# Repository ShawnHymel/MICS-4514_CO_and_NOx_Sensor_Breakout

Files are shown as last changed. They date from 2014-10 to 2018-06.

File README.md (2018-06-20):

MICS-4514_CO_and_NOx_Sensor_Breakout
==========================

Breakout board for the MiCS-4514 CO and NOx gas sensor.

Calculating CO and NOx Values
-----------------------------

I have not been able to work on this project in a few years, and at this point, I don't think I'll be able to continue the project in the foreseeable future (i.e. consider it a dead project). However, you are more than welcome to use the boards to make your own breakouts. If you are looking for example code on how to get CO and NOx readings, please [see this aricle](http://myscope.net/auswertung-der-airpi-gas-sensoren/) (in German, but the math should still work :).

Other example projects that calculate CO and NOx that might help you:

https://github.com/panStamp/swap/blob/master/examples/respira/sensor.h 
https://github.com/panStamp/swap/blob/master/examples/respira/sensor.ino
https://github.com/NationalAssociationOfRealtors/PiAQ/commit/cc4948cea3390a6df1ba7199cfc5aaa81f1222a6 
https://github.com/EmwareStd/Ventilation-system.-CO-and-NOx-control./blob/develop/Firmware/Sensor_module/Sensor_module.ino
https://github.com/Edvardoh/ArduinoAirQuality/blob/master/Arduino_NO2_CO_test/Arduino_NO2_CO_test.ino

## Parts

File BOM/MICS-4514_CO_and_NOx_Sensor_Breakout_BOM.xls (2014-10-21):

Qty | REFDES | Part | Value | Device | Package | Mfg Part No. | Vendor Part No. | Source
1 | C1 | Capacitor | 10uF | CAP0805 | 805 | LMK212BJ106KG-T | 587-1300-1-ND | http://www.digikey.com/product-detail/en/LMK212BJ106KG-T/587-1300-1-ND/931077
1 | JP1 | Header | 5 pin, 0.100” pitch | M05LOCK | 1X05_LOCK | 61300511121 | 732-5318-ND | http://www.digikey.com/product-detail/en/61300511121/732-5318-ND/4846831
1 | Q2 | Transistor | MOSFET, N-Ch Enh | MOSFET-NCHANNELBSS138 | SOT23-3 | BSS138LT1G | BSS138LT1GOSCT-ND | http://www.digikey.com/product-detail/en/BSS138LT1G/BSS138LT1GOSCT-ND/917858
2 | R1, R6 | Resistor | 82 | RESISTOR0805-RES | 805 | CRCW080582R0FKEA | 541-82.0CCT-ND | http://www.digikey.com/product-detail/en/CRCW080582R0FKEA/541-82.0CCT-ND/1180659
1 | R2 | Resistor | 51 | RESISTOR0603 | 0603-RES | RC0603FR-0751RL | 311-51.0HRCT-ND | http://www.digikey.com/product-detail/en/RC0603FR-0751RL/311-51.0HRCT-ND/730228
1 | R3 | Resistor | 100 | 100OHM1/10W1%(0603) | 0603-RES | RC0603FR-07100RL | 311-100HRCT-ND | http://www.digikey.com/product-detail/en/RC0603FR-07100RL/311-100HRCT-ND/729835
1 | R4 | Resistor | 100k | 100KOHM1/10W1%(0603) | 0603-RES | RC0603FR-07100KL | 311-100KHRCT-ND | http://www.digikey.com/product-detail/en/RC0603FR-07100KL/311-100KHRCT-ND/729836
1 | R5 | Resistor | 22K | 22KOHM1/10W1%(0603) | 0603-RES | RC0603FR-0722KL | 311-22.0KHRCT-ND | http://www.digikey.com/product-detail/en/RC0603FR-0722KL/311-22.0KHRCT-ND/730003
1 | R7 | Resistor | 47K | 47KOHM1/10W1%(0603) | 0603-RES | RC0603FR-0747KL | 311-47.0KHRCT-ND | http://www.digikey.com/product-detail/en/RC0603FR-0747KL/311-47.0KHRCT-ND/730200
1 | U1 | Sensor |  | MICS-4514 | MICS_10-SMD | MICS-4514 | MICS-4514 | http://sgx.cdistore.com/ProductDetail/MICS4514-SGX-Sensortech-Limited/333417/#.VEaWCvnF924

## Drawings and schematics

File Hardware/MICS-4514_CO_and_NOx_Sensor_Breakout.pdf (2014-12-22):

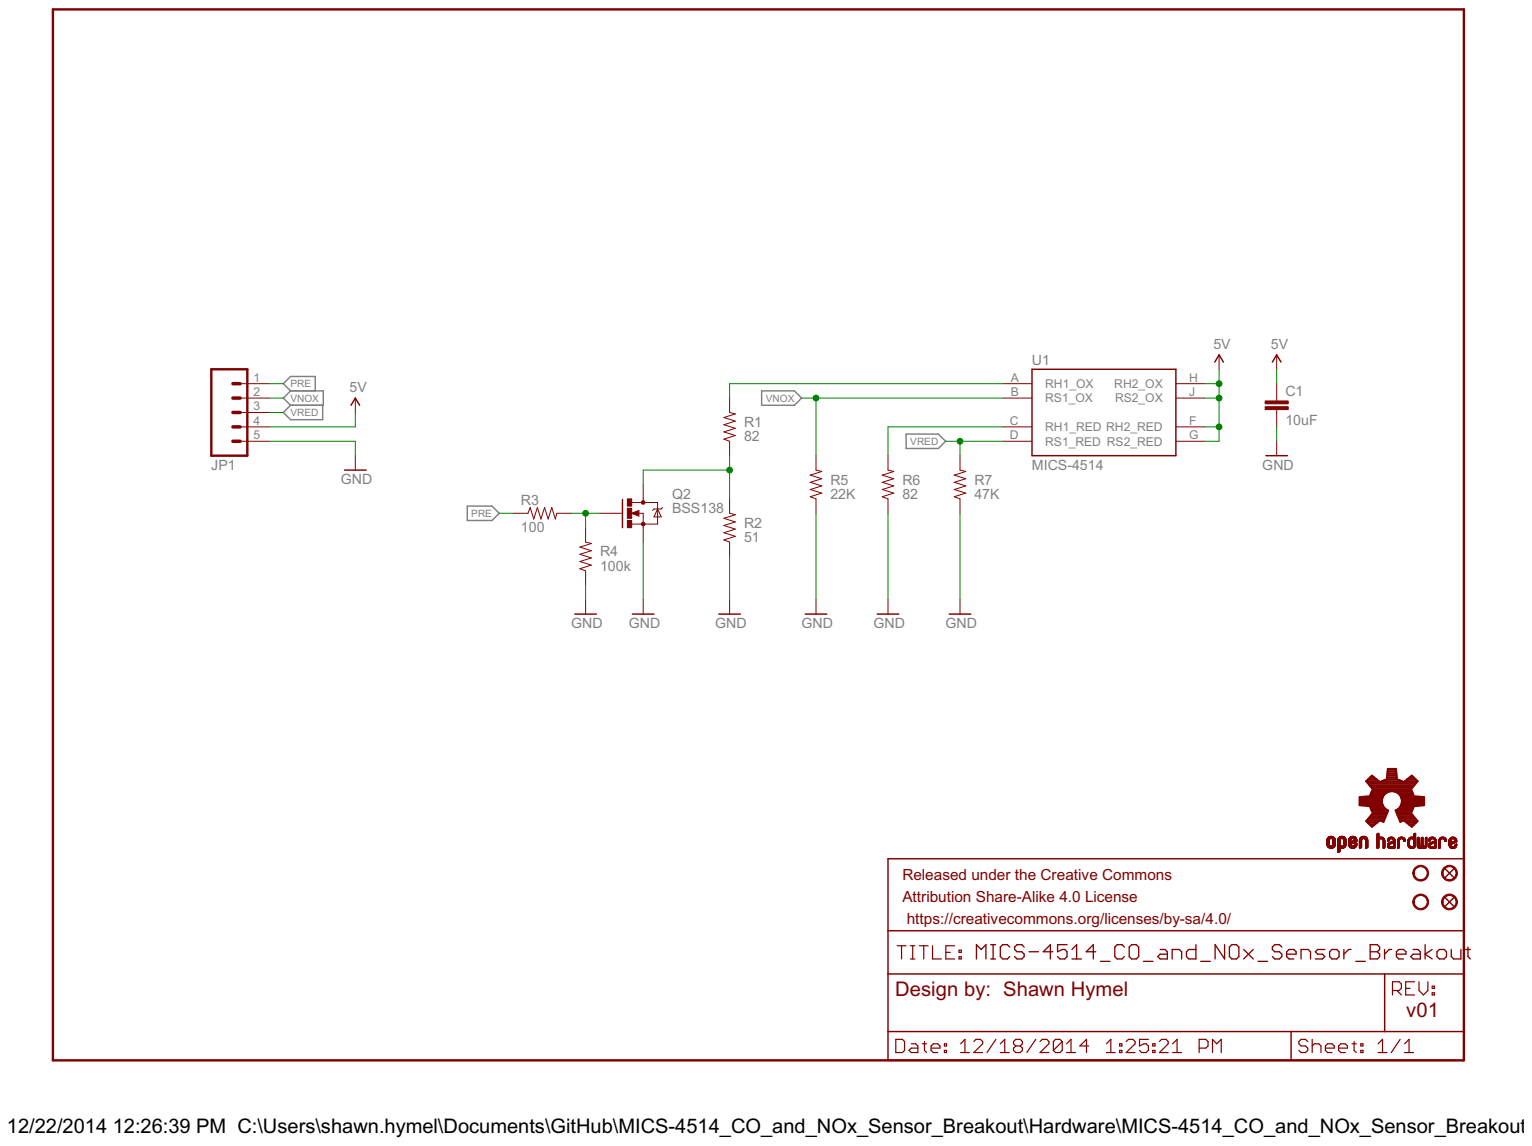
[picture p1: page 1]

Released under the Creative Commons Attribution Share-Alike 4.0 License

https://creativecommons.org/licenses/by-sa/4.0/

12/22/2014 12:26:39 PM C:\Users\shawn.hymel\Documents\GitHub\MICS-4514_CO_and_NOx_Sensor_Breakout\Hardware\MICS-4514_CO_and_NOx_Sensor_Breakout.sch (Sheet: 1/1)

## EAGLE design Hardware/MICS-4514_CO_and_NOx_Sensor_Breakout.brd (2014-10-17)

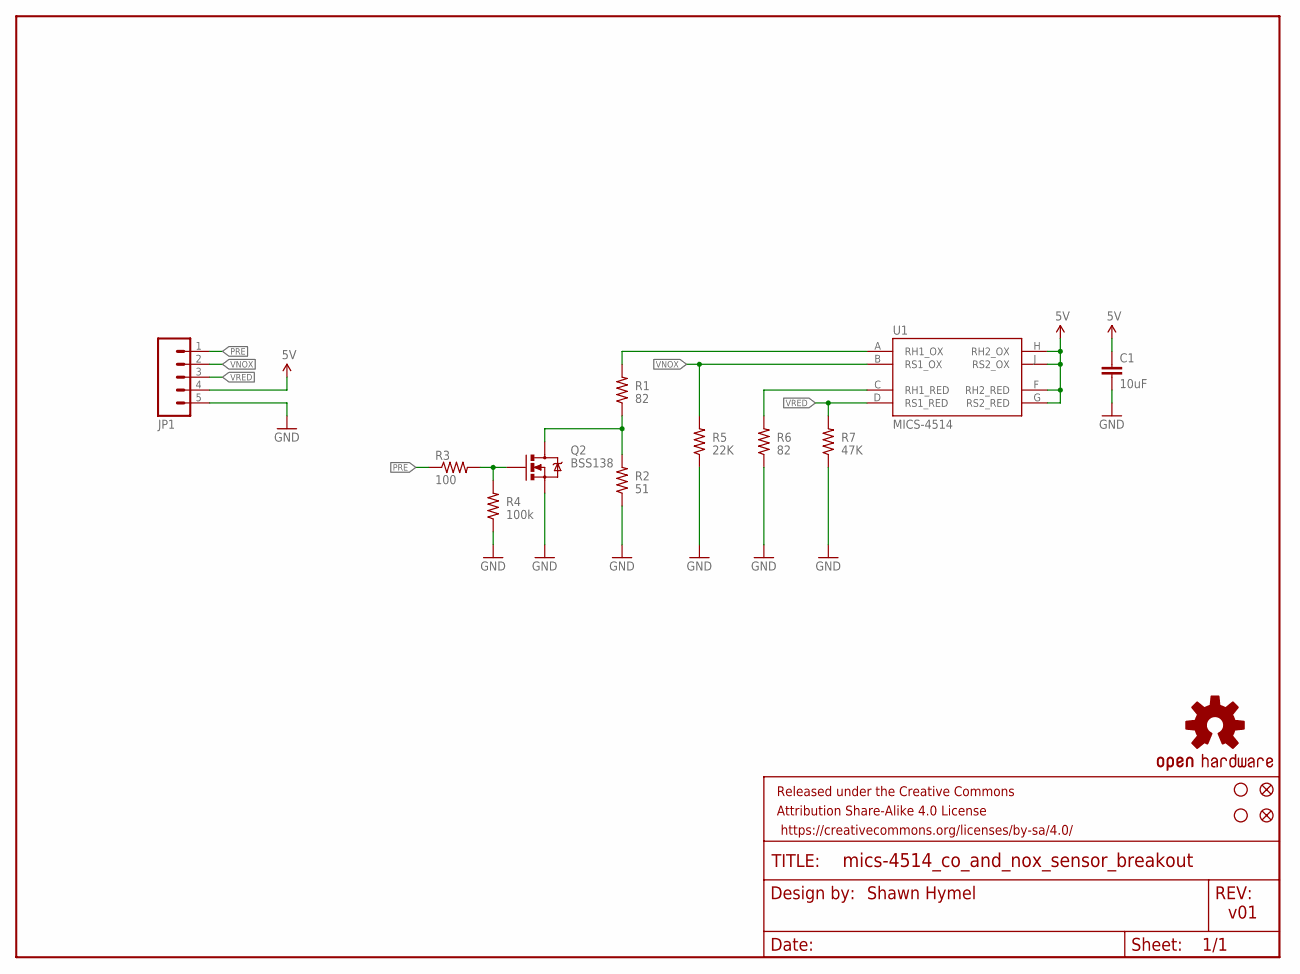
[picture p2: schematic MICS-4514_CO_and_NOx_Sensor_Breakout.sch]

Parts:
C1: 10uF; 0805
FID1, FID2: FIDUCIAL1X2; FIDUCIAL-1X2
FRAME1: FRAME-LETTER; CREATIVE_COMMONS
JP1: M05LOCK; 1X05_LOCK
LOGO1: OSHW-LOGOS; OSHW-LOGO-S
Q2: MOSFET-NCHANNELBSS138; SOT23-3
R1, R6: 82; 0805
R2: 51; 0603-RES
R3: 100; 0603-RES
R4: 100k; 0603-RES
R5: 22K; 0603-RES
R7: 47K; 0603-RES
STANDOFF3, STANDOFF5: STAND-OFF
U1: MICS-4514; MICS_10-SMD

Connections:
5V: C1.1, JP1.4, U1.F (RH2_RED), U1.G (RS2_RED), U1.H (RH2_OX), U1.J (RS2_OX)
GND: C1.2, JP1.5, Q2.2 (S), R2.1, R4.1, R5.1, R6.1, R7.1
unnamed: R1.2, U1.A (RH1_OX)
unnamed: R6.2, U1.C (RH1_RED)
unnamed: Q2.1 (G), R3.2, R4.2
unnamed: Q2.3 (D), R1.1, R2.2
PRE: JP1.1, R3.1
VNOX: JP1.2, R5.2, U1.B (RS1_OX)
VRED: JP1.3, R7.2, U1.D (RS1_RED)

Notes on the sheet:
v01
Shawn Hymel

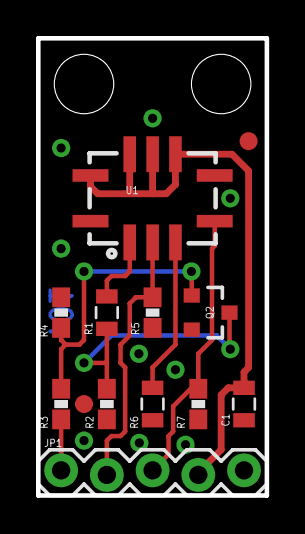
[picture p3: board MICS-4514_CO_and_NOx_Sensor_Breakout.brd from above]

Board: 2 copper layers, 12.7 x 25.4 mm, 17 parts (1 on the bottom side), 9 nets.

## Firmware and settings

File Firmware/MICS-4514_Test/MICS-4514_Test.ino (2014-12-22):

#define PRE_PIN          8
#define VNOX_PIN         A0
#define VRED_PIN         A1

#define PRE_HEAT_SECONDS 10

int vnox_value = 0;
int vred_value = 0;

void setup() {
  
  // Setup preheater pin
  pinMode(PRE_PIN, OUTPUT);
  
  // Initialize serial port
  Serial.begin(9600);
  Serial.println("MiCS-4514 Test Read");
  Serial.print("Preheating...");

  // Wait for preheating
  digitalWrite(PRE_PIN, 1);
  delay(PRE_HEAT_SECONDS * 1000);
  digitalWrite(PRE_PIN, 0);
  Serial.println("Done");
}

void loop() {
  
  // Read analog values, print them out, and wait
  vnox_value = analogRead(VNOX_PIN);
  vred_value = analogRead(VRED_PIN);
  Serial.print("Vnox: ");
  Serial.print(vnox_value, DEC);
  Serial.print(" Vred: ");
  Serial.println(vred_value, DEC);
  delay(1000);
}

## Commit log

2014-10-16 Copied in previous work.
    [MICS-4514_CO_and_NOx_Sensor_Breakout.sch]
2014-10-16 Deleted original files.
    [MICS-4514_CO_and_NOx_Sensor_Breakout.sch]
2014-10-16 Re-added files from previous work.
    [MICS-4514_CO_and_NOx_Sensor_Breakout.sch]
2014-10-16 Finished schematic. Added pre-heating FET.
    [MICS-4514_CO_and_NOx_Sensor_Breakout.sch]
2014-10-17 Created initial layout.
    [MICS-4514_CO_and_NOx_Sensor_Breakout.brd, MICS-4514_CO_and_NOx_Sensor_Breakout.sch]
2014-10-21 Added BOM
    [MICS-4514_CO_and_NOx_Sensor_Breakout_BOM.xls]
2014-12-22 Added test Arduino code and photos.

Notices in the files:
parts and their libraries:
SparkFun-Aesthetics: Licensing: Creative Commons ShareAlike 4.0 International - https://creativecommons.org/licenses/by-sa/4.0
